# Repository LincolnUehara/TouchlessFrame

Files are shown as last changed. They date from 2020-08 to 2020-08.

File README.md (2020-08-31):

# Touchless Frame
Customizable frame made of infrared sensors to promote contactless interface

<p align="center">

</p>

This repository contains Kicad and Freecad related files to Touchless Frame Project.

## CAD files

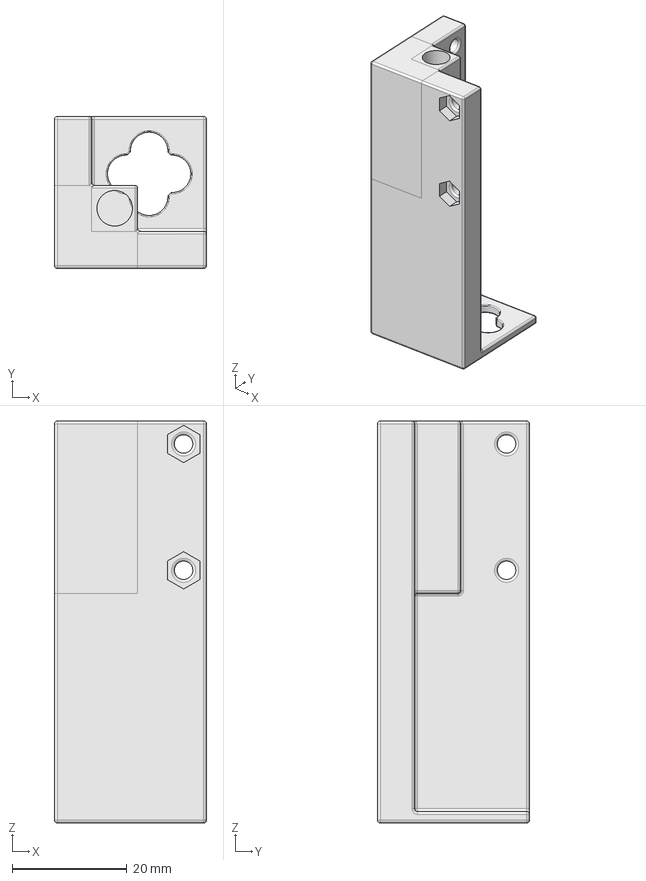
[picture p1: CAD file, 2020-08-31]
freecad/supportMain_v1.FCStd
26.5 x 26.5 x 70.0 mm

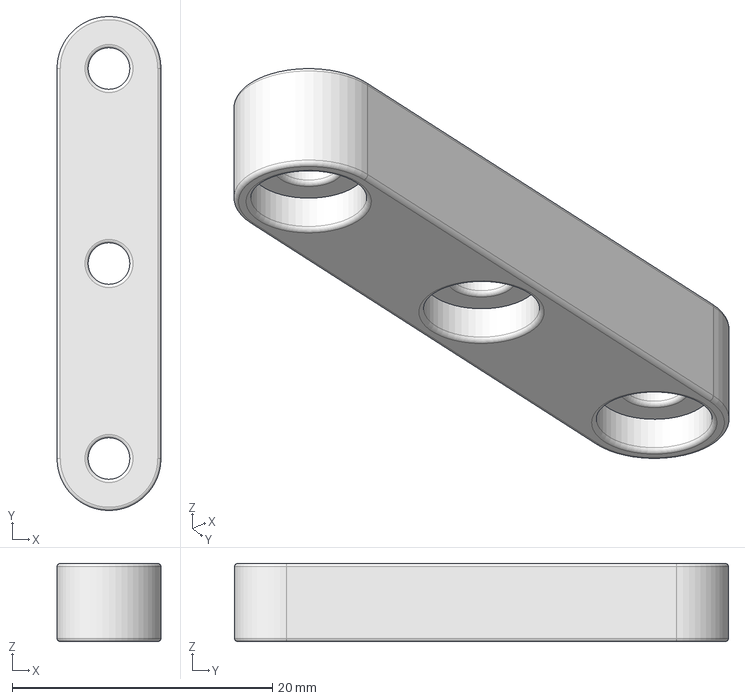
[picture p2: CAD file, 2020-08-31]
freecad/bar1unit_v1.FCStd
8.00 x 38.0 x 6.00 mm

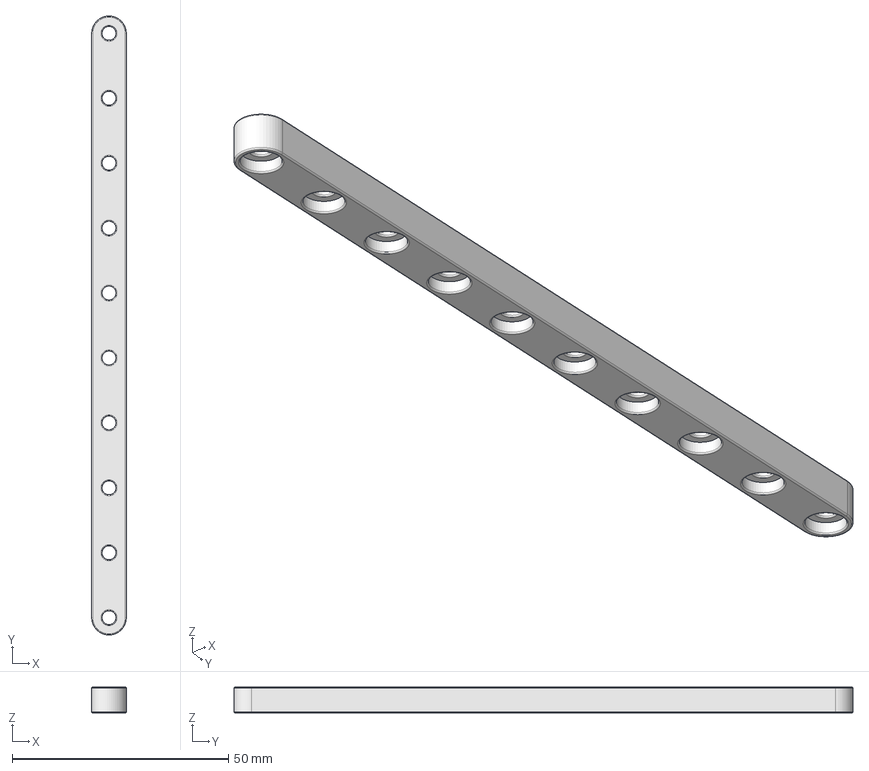
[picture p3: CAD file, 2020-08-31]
freecad/bar8units_v1.FCStd
8.00 x 143.0 x 6.00 mm

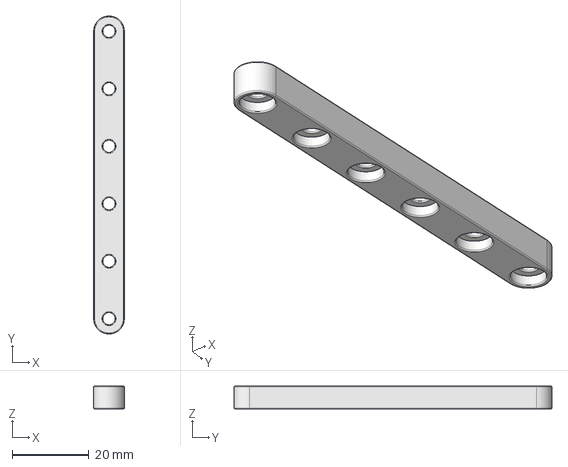
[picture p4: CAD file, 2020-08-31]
freecad/bar4units_v1.FCStd
8.00 x 83.0 x 6.00 mm

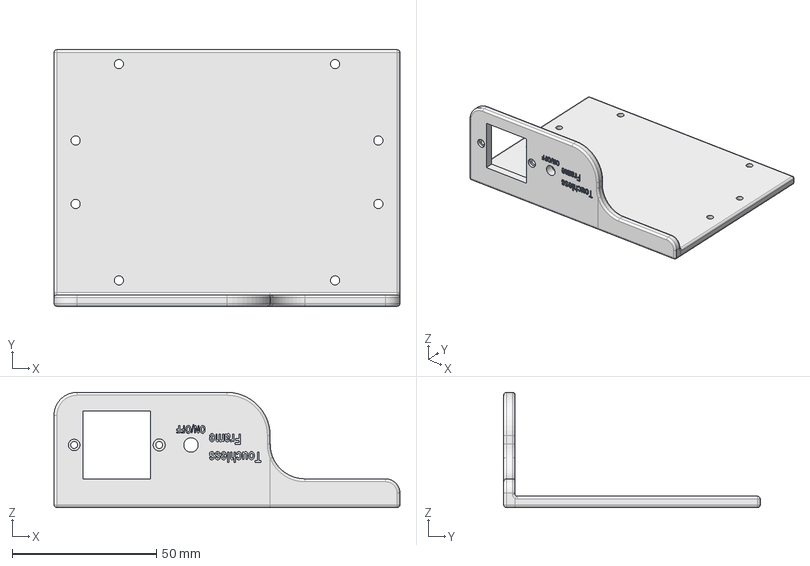
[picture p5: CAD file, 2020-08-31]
freecad/supportBase_V1.FCStd
120.0 x 89.0 x 40.0 mm

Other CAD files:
freecad/STL/bar1unit_V1.stl
freecad/STL/bar4units_V1.stl
freecad/STL/bar8units_V1.stl
freecad/STL/supportBase_V1.stl
freecad/STL/supportMain_V1.stl

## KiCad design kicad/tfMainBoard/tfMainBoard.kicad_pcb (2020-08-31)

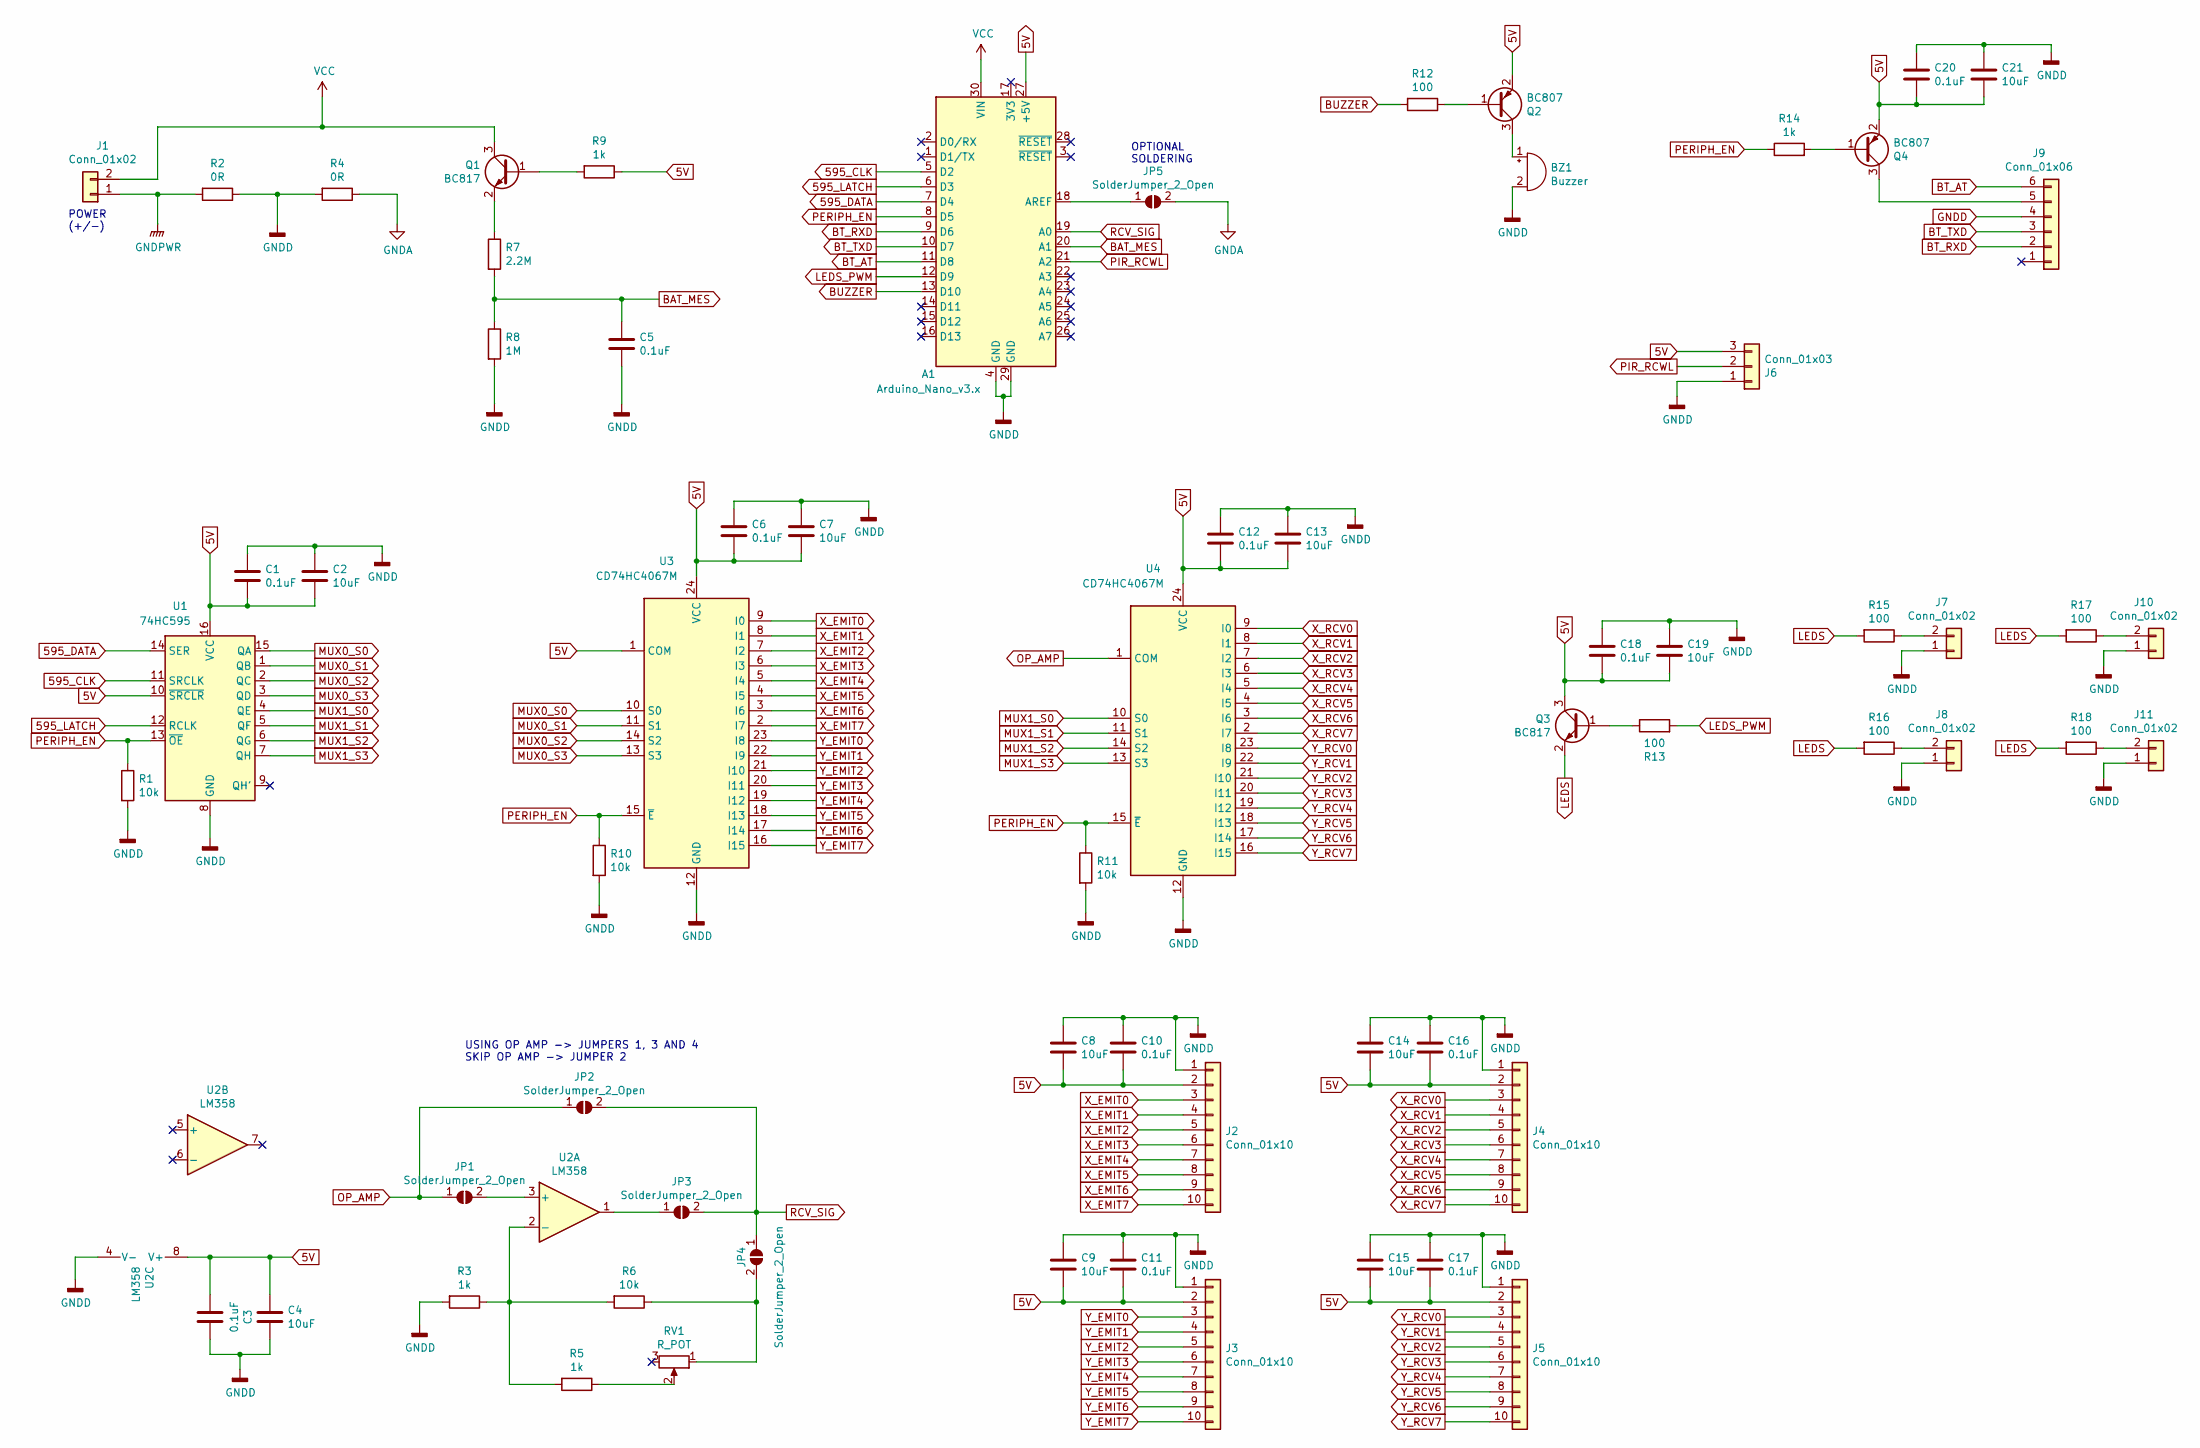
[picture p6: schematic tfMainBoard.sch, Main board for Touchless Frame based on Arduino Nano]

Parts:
A1: Arduino_Nano_v3.x; Arduino_Nano
BZ1: Buzzer; Buzzer_12x9.5RM7.6
C1, C3, C5, C6, C10, C11, C12, C16, C17, C18, C20: 0.1uF; C_0603_1608Metric
C2, C4, C7, C8, C9, C13, C14, C15, C19, C21: 10uF; C_0603_1608Metric
J1, J7, J8, J10, J11: Conn_01x02; PinHeader_1x02_P2.54mm_Vertical
J2, J3, J4, J5: Conn_01x10; PinHeader_1x10_P2.54mm_Vertical
J6: Conn_01x03; PinHeader_1x03_P2.54mm_Vertical
J9: Conn_01x06; PinHeader_1x06_P2.54mm_Vertical
JP1, JP2, JP3, JP4, JP5: SolderJumper_2_Open; SolderJumper-2_P1.3mm_Open_RoundedPad1.0x1.5mm
Q1, Q3: BC817; SOT-23
Q2, Q4: BC807; SOT-23
R1, R6, R10, R11: 10k; R_0603_1608Metric
R2, R4: 0R; R_1210_3225Metric
R3, R5, R9, R14: 1k; R_0603_1608Metric
R7: 2.2M; R_0603_1608Metric
R8: 1M; R_0603_1608Metric
R12, R13, R15, R16, R17, R18: 100; R_0603_1608Metric
RV1: R_POT; Potentiometer_Bourns_3214X_Vertical
U1: 74HC595; SOIC-16_3.9x9.9mm_P1.27mm
U2: LM358; SOIC-8_3.9x4.9mm_P1.27mm
U3, U4: CD74HC4067M; SSOP-24_5.3x8.2mm_P0.65mm

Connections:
5V: A1.27 (+5V), C1.2, C2.2, C3.2, C4.1, C6.2, C7.2, C8.2, C9.2, C10.2, C11.2, C12.2, C13.2, C14.2, C15.2, C16.2, C17.2, C18.2, C19.2, C20.2, C21.2, J2.2, J3.2, J4.2, J5.2, J6.3, Q2.2 (E), Q3.3 (C), Q4.2 (E), R9.1, U1.10 (~SRCLR), U1.16 (VCC), U2.8 (V+), U3.1 (COM), U3.24 (VCC), U4.24 (VCC)
595_CLK: A1.5 (D2), U1.11 (SRCLK)
595_DATA: A1.7 (D4), U1.14 (SER)
595_LATCH: A1.6 (D3), U1.12 (RCLK)
BAT_MES: A1.20 (A1), C5.1, R7.2, R8.1
BT_AT: A1.11 (D8), J9.6
BT_RXD: A1.9 (D6), J9.2
BT_TXD: A1.10 (D7), J9.3
BUZZER: A1.13 (D10), R12.2
GNDA: JP5.2 (B), R4.1
GNDD: A1.4 (GND), A1.29 (GND), BZ1.2 (+), C1.1, C2.1, C3.1, C4.2, C5.2, C6.1, C7.1, C8.1, C9.1, C10.1, C11.1, C12.1, C13.1, C14.1, C15.1, C16.1, C17.1, C18.1, C19.1, C20.1, C21.1, J2.1, J3.1, J4.1, J5.1, J6.1, J7.1, J8.1, J9.4, J10.1, J11.1, R1.2, R2.1, R3.2, R4.2, R8.2, R10.2, R11.2, U1.8 (GND), U2.4 (V-), U3.12 (GND), U4.12 (GND)
GNDPWR: J1.1, R2.2
LEDS: Q3.2 (E), R15.2, R16.2, R17.2, R18.2
LEDS_PWM: A1.12 (D9), R13.2
MUX0_S0: U1.15 (QA), U3.10 (S0)
MUX0_S1: U1.1 (QB), U3.11 (S1)
MUX0_S2: U1.2 (QC), U3.14 (S2)
MUX0_S3: U1.3 (QD), U3.13 (S3)
MUX1_S0: U1.4 (QE), U4.10 (S0)
MUX1_S1: U1.5 (QF), U4.11 (S1)
MUX1_S2: U1.6 (QG), U4.14 (S2)
MUX1_S3: U1.7 (QH), U4.13 (S3)
unnamed: A1.18 (AREF), JP5.1 (A)
unnamed: BZ1.1 (-), Q2.3 (C)
unnamed: J7.2, R15.1
unnamed: J8.2, R16.1
unnamed: J9.5, Q4.3 (C)
unnamed: J10.2, R17.1
unnamed: J11.2, R18.1
unnamed: JP1.2 (B), U2.3 (+)
unnamed: JP3.1 (A), U2.1
unnamed: JP4.2 (B), R6.1, RV1.1
unnamed: Q1.1 (B), R9.2
unnamed: Q1.2 (E), R7.1
unnamed: Q2.1 (B), R12.1
unnamed: Q3.1 (B), R13.1
unnamed: Q4.1 (B), R14.2
unnamed: R3.1, R5.2, R6.2, U2.2 (-)
unnamed: R5.1, RV1.2
OP_AMP: JP1.1 (A), JP2.1 (A), U4.1 (COM)
PERIPH_EN: A1.8 (D5), R1.1, R10.1, R11.1, R14.1, U1.13 (~OE), U3.15 (~E), U4.15 (~E)
PIR_RCWL: A1.21 (A2), J6.2
RCV_SIG: A1.19 (A0), JP2.2 (B), JP3.2 (B), JP4.1 (A)
VCC: A1.30 (VIN), J1.2, Q1.3 (C)
X_EMIT0: J2.3, U3.9 (I0)
X_EMIT1: J2.4, U3.8 (I1)
X_EMIT2: J2.5, U3.7 (I2)
X_EMIT3: J2.6, U3.6 (I3)
X_EMIT4: J2.7, U3.5 (I4)
X_EMIT5: J2.8, U3.4 (I5)
X_EMIT6: J2.9, U3.3 (I6)
X_EMIT7: J2.10, U3.2 (I7)
X_RCV0: J4.3, U4.9 (I0)
X_RCV1: J4.4, U4.8 (I1)
X_RCV2: J4.5, U4.7 (I2)
X_RCV3: J4.6, U4.6 (I3)
X_RCV4: J4.7, U4.5 (I4)
X_RCV5: J4.8, U4.4 (I5)
X_RCV6: J4.9, U4.3 (I6)
X_RCV7: J4.10, U4.2 (I7)
Y_EMIT0: J3.3, U3.23 (I8)
Y_EMIT1: J3.4, U3.22 (I9)
Y_EMIT2: J3.5, U3.21 (I10)
Y_EMIT3: J3.6, U3.20 (I11)
Y_EMIT4: J3.7, U3.19 (I12)
Y_EMIT5: J3.8, U3.18 (I13)
Y_EMIT6: J3.9, U3.17 (I14)
Y_EMIT7: J3.10, U3.16 (I15)
Y_RCV0: J5.3, U4.23 (I8)
Y_RCV1: J5.4, U4.22 (I9)
Y_RCV2: J5.5, U4.21 (I10)
Y_RCV3: J5.6, U4.20 (I11)
Y_RCV4: J5.7, U4.19 (I12)
Y_RCV5: J5.8, U4.18 (I13)
Y_RCV6: J5.9, U4.17 (I14)
Y_RCV7: J5.10, U4.16 (I15)

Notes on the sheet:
POWER (+/-)
OPTIONAL SOLDERING
USING OP AMP -> JUMPERS 1, 3 AND 4 SKIP OP AMP -> JUMPER 2

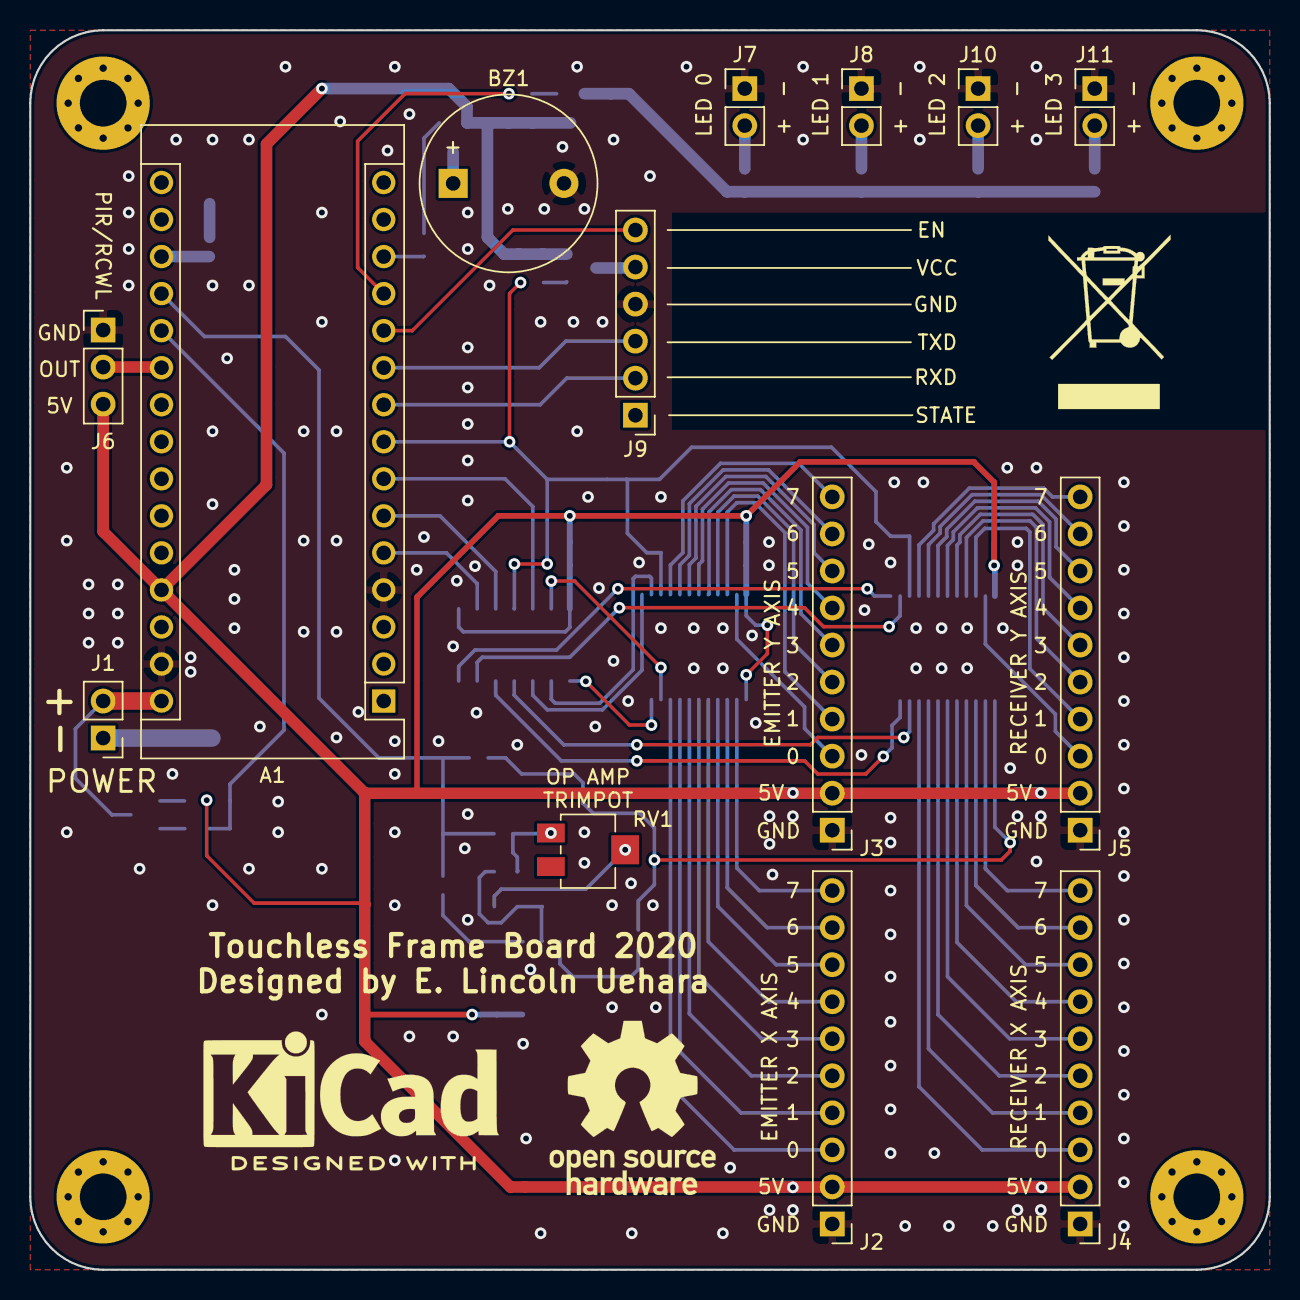
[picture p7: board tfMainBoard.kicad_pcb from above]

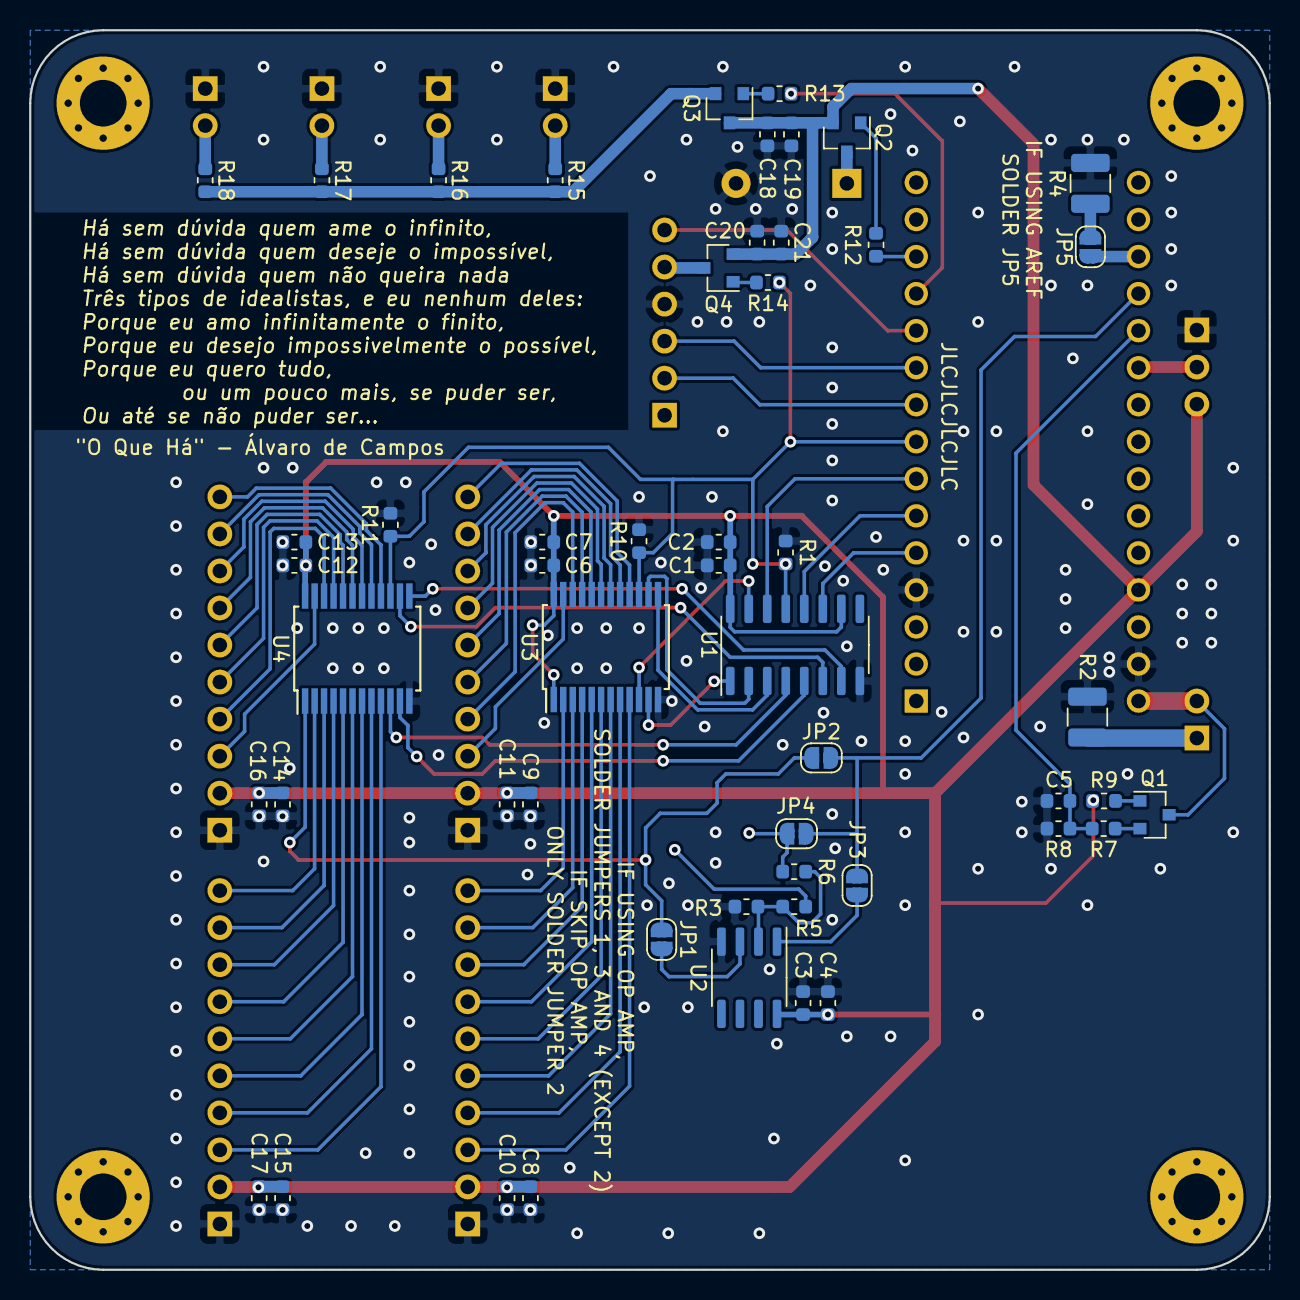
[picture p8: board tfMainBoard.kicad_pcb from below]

Board: 2 copper layers, 85.0 x 85.0 mm, 66 parts (52 on the bottom side), 76 nets.

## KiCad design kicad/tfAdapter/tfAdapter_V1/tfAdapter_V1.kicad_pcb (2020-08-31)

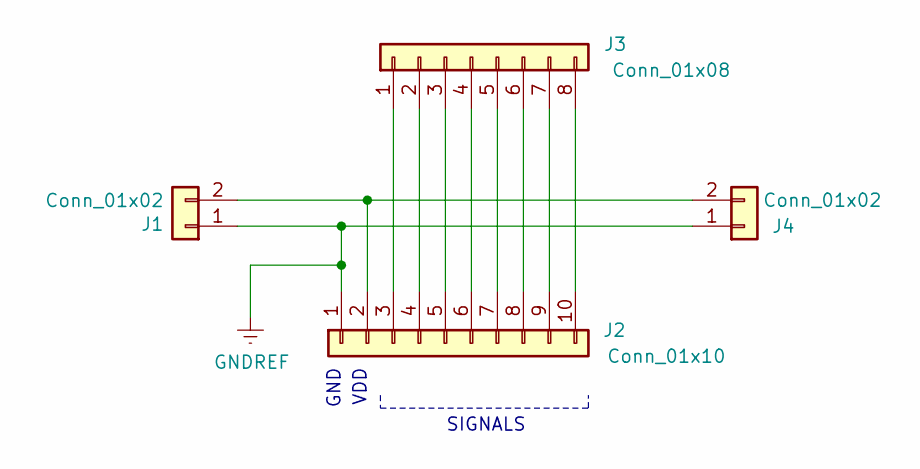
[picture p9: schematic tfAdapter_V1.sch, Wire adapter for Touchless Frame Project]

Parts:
J1, J4: Conn_01x02; PinHeader_1x02_P2.54mm_Vertical
J2: Conn_01x10; PinHeader_1x10_P2.54mm_Vertical
J3: Conn_01x08; PinHeader_1x08_P2.54mm_Vertical

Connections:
GNDREF: J1.1, J2.1, J4.1
unnamed: J1.2, J2.2, J4.2
unnamed: J2.3, J3.1
unnamed: J2.4, J3.2
unnamed: J2.5, J3.3
unnamed: J2.6, J3.4
unnamed: J2.7, J3.5
unnamed: J2.8, J3.6
unnamed: J2.9, J3.7
unnamed: J2.10, J3.8

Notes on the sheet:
VDD
GND
SIGNALS

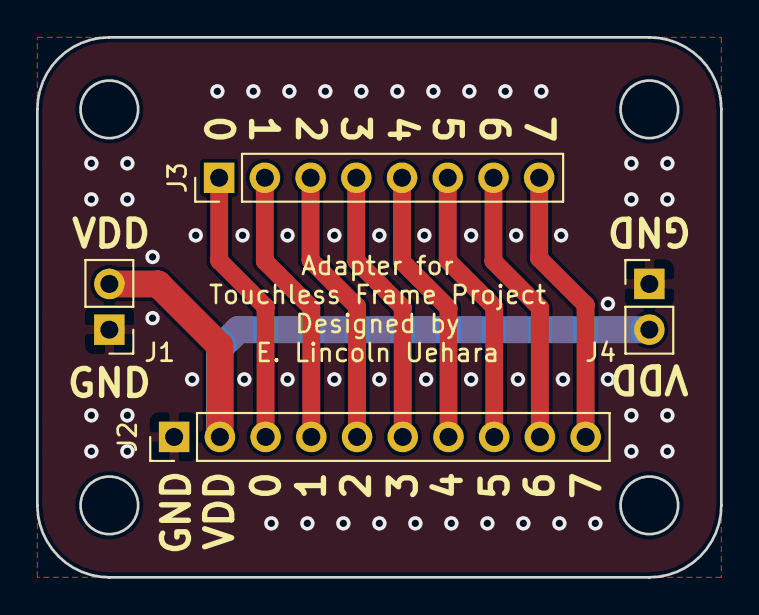
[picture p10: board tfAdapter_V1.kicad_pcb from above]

Board: 2 copper layers, 38.0 x 30.0 mm, 4 parts (0 on the bottom side), 10 nets.

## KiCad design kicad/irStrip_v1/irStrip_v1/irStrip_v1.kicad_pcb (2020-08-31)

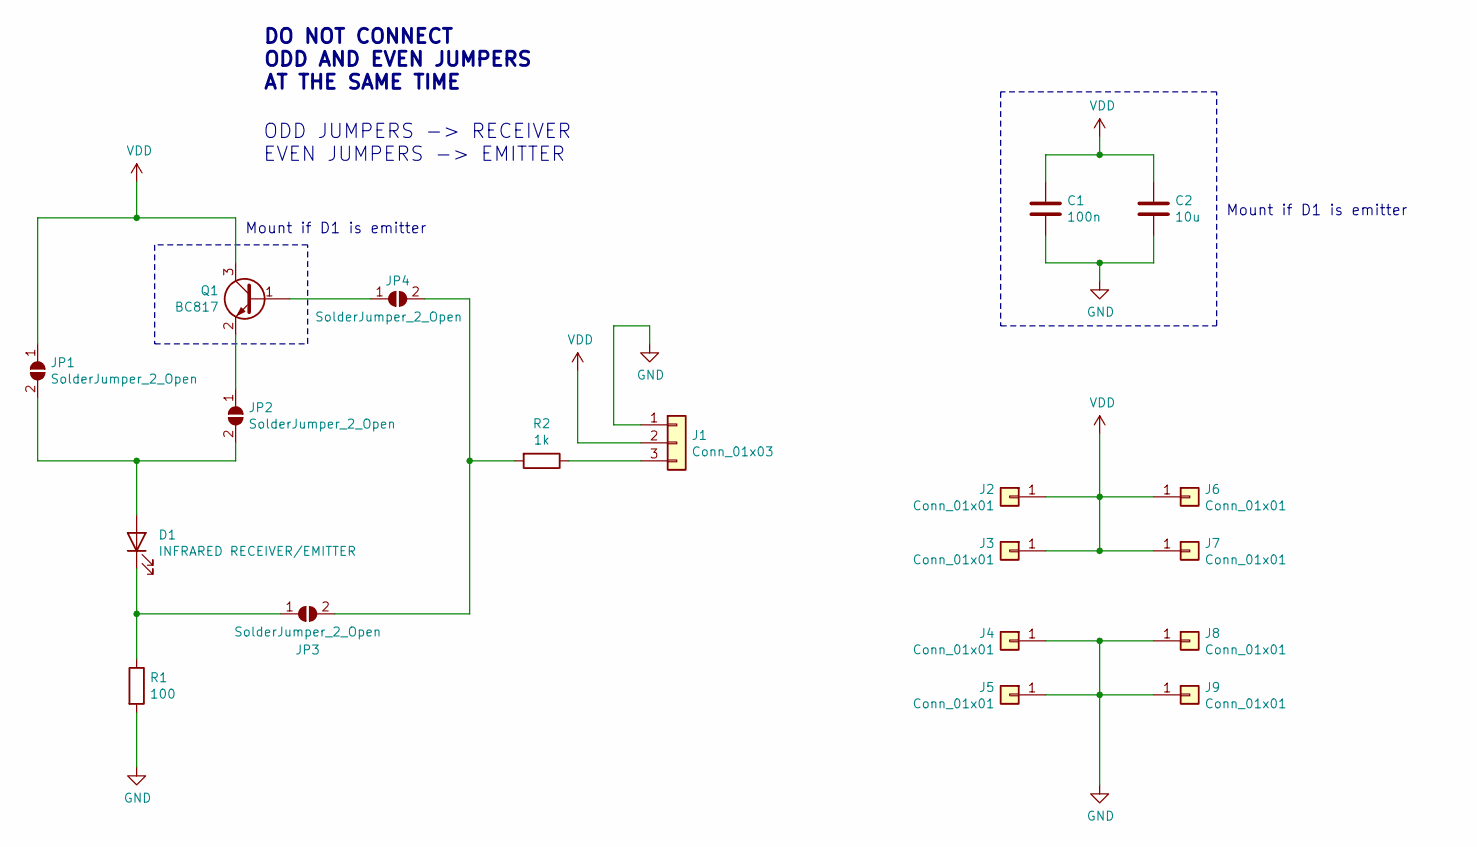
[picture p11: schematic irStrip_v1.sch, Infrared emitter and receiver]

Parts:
C1: 100n; C_0603_1608Metric
C2: 10u; C_0603_1608Metric
D1: INFRARED RECEIVER/EMITTER; LED_D5.0mm
J1: Conn_01x03; PinHeader_1x03_P2.54mm_Vertical
J2, J3, J4, J5, J6, J7, J8, J9: Conn_01x01; TestPoint_Pad_2.0x2.0mm
JP1, JP2, JP3, JP4: SolderJumper_2_Open; SolderJumper-2_P1.3mm_Open_RoundedPad1.0x1.5mm
Q1: BC817; SOT-23
R1: 100; R_0603_1608Metric
R2: 1k; R_0603_1608Metric

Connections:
GND: C1.2, C2.2, J1.1, J4.1, J5.1, J8.1, J9.1, R1.2
unnamed: D1.1 (K), JP3.1 (A), R1.1
unnamed: D1.2 (A), JP1.2 (B), JP2.2 (B)
unnamed: J1.3, R2.1
unnamed: JP2.1 (A), Q1.2 (E)
unnamed: JP3.2 (B), JP4.2 (B), R2.2
unnamed: JP4.1 (A), Q1.1 (B)
VDD: C1.1, C2.1, J1.2, J2.1, J3.1, J6.1, J7.1, JP1.1 (A), Q1.3 (C)

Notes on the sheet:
DO NOT CONNECT ODD AND EVEN JUMPERS AT THE SAME TIME
ODD JUMPERS -> RECEIVER EVEN JUMPERS -> EMITTER
Mount if D1 is emitter

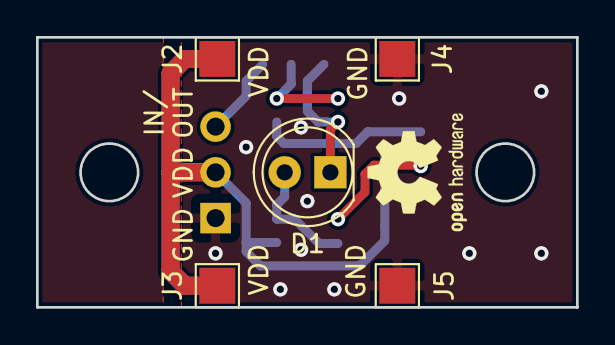
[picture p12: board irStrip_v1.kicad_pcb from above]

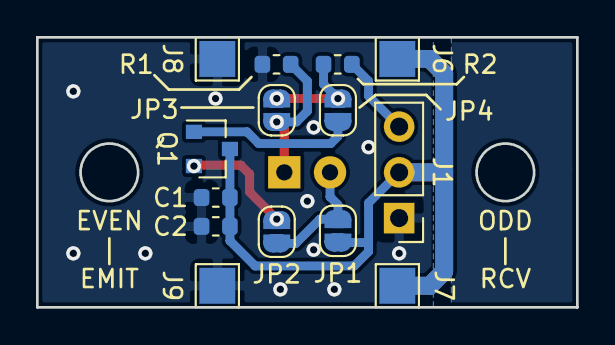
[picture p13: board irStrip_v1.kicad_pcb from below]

Board: 2 copper layers, 30.0 x 15.0 mm, 19 parts (14 on the bottom side), 8 nets.

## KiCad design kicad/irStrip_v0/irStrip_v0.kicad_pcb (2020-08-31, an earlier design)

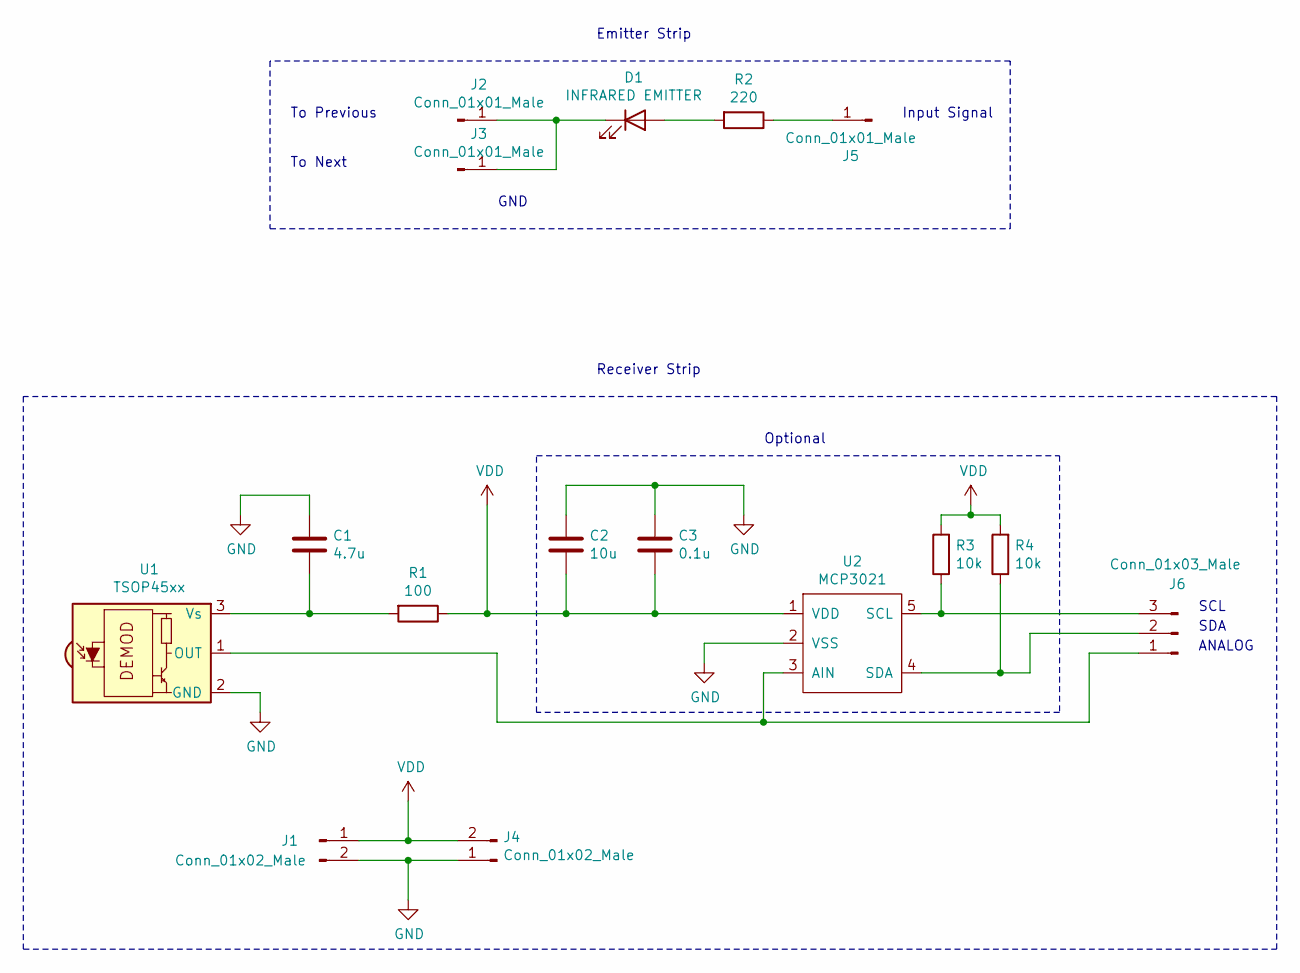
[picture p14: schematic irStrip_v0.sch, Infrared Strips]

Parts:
C1: 4.7u; C_0603_1608Metric
C2: 10u; C_0603_1608Metric
C3: 0.1u; C_0603_1608Metric
D1: INFRARED EMITTER; LED_D5.0mm
J1, J4: Conn_01x02_Male; PinHeader_1x02_P2.54mm_Vertical
J2, J3, J5: Conn_01x01_Male; PinHeader_1x01_P2.54mm_Vertical
J6: Conn_01x03_Male; PinHeader_1x03_P2.54mm_Vertical
R1: 100; R_0603_1608Metric
R2: 220; R_0603_1608Metric
R3, R4: 10k; R_0603_1608Metric
U1: TSOP45xx; infrared_lie_down
U2: MCP3021; SOT-23-5

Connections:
GND: C1.1, C2.1, C3.1, J1.2, J4.1, U1.2 (GND), U2.2 (VSS)
unnamed: C1.2, R1.2, U1.3 (Vs)
unnamed: D1.1 (K), J2.1, J3.1
unnamed: D1.2 (A), R2.2
unnamed: J5.1, R2.1
unnamed: J6.1, U1.1 (OUT), U2.3 (AIN)
unnamed: J6.2, R4.1, U2.4 (SDA)
unnamed: J6.3, R3.1, U2.5 (SCL)
VDD: C2.2, C3.2, J1.1, J4.2, R1.1, R3.2, R4.2, U2.1 (VDD)

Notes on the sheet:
Optional
To Previous
To Next
Input Signal
Emitter Strip
Receiver Strip
GND
SCL
SDA
ANALOG

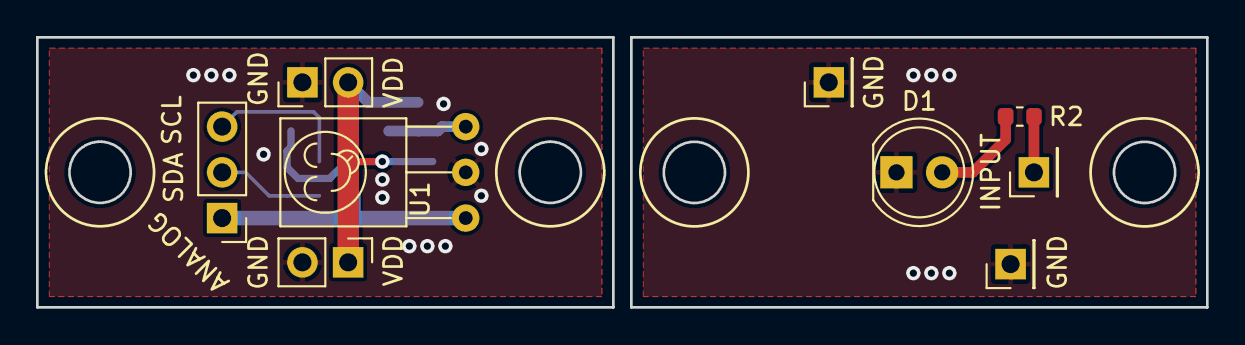
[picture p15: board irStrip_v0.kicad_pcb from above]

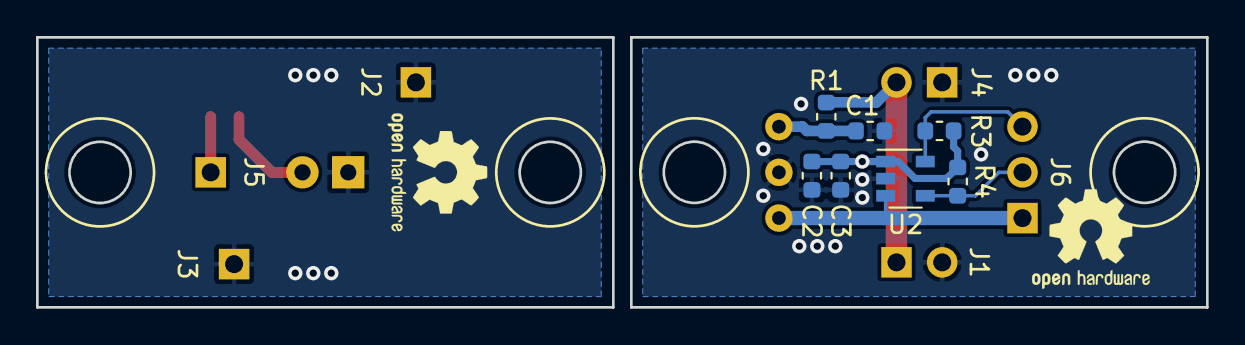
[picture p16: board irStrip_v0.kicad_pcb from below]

Board: 2 copper layers, 65.0 x 15.0 mm, 16 parts (7 on the bottom side), 9 nets.
